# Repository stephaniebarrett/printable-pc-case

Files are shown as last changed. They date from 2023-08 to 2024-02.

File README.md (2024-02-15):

# 3D Printable Rackmount PC/Server Case using [OpenSCAD](https://openscad.org/).
## WIP
The goal of this project originally was to create OpenSCAD modules of PC components to facilitate the design of a modular rack-mountable computer chassis. But once that was complete, I began designing a chassis and somewhere to store it; so for now, here we are. 2.5 versions in and I still feel like this is very much a work in progress. As I complete test prints, and have new ideas, I will continue to iterate on the case design.

## Notes
### V1
While doing a full test print/fit, there were several issues with warping (especially the corner pieces) and cracking when transitioning from printing floor + walls to just the walls. However, they didn't seem to affect the build at all. The rear wall was the most fragile with fan/io/psu cutouts and some chunkier pieces to bolt sections together; I had one of those chunky pieces break off, and some issues with support material not cooperating while printing. The honeycomb fill needs some work, while nocking out its support material, most of the honeycomb broke off on 2 of the 3 fan openings.  The 3U test case is currently mounted in my rack with x4 Rack Studs in the center of the first and third 'U's. It has been extremely stable, however I still have concerns about the PSU somewhat unsupported at the rear of the case.

#### Exporting (batch file)
```
export.bat [options] main.scad
Allowed options:
	-t arg		Specifies the type of file to export: stl, png (may be used multiple times)
	-m arg		Specifies the type of model to export: cage, joinery, rack (may be used multiple times)
	-h arg		0 will remove the honeycomb fill, 1 will keep it.
```

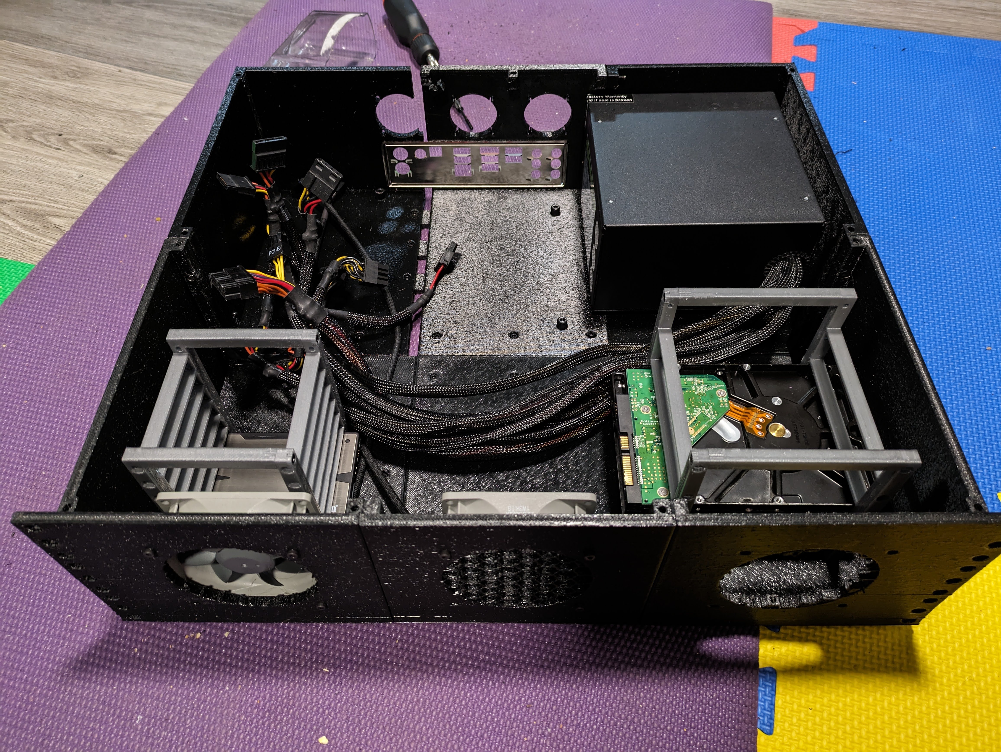
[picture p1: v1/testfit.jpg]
Chassis Test Fit V1 Test Fit


### V2 & V2-Compact
A complete redesign has enabled me to mitigate most of the cracking, warping, and support issues by building panels rather than sections. This means all of the panels can be printed flat on the build plate and the hex sections come out quite well. I moved the PSU to the front of the case, which required standing it on it's side to fit beside an ATX mainboard within a 19" rack. That also means I've had to go from a 3U design to a 4U to fit it on it's side, and you'll need to plug it in at the front. However, all of the heavy components are now at the front of the case, close to the supports, which has allowed some thinner walls and a somewhat simpler system of joining the panels together.

The compact version of the V2 case is almost identical. The most obvious difference is that the HDDs are mounted above the mainboard, allowing the case depth to be reduced by about 115mm

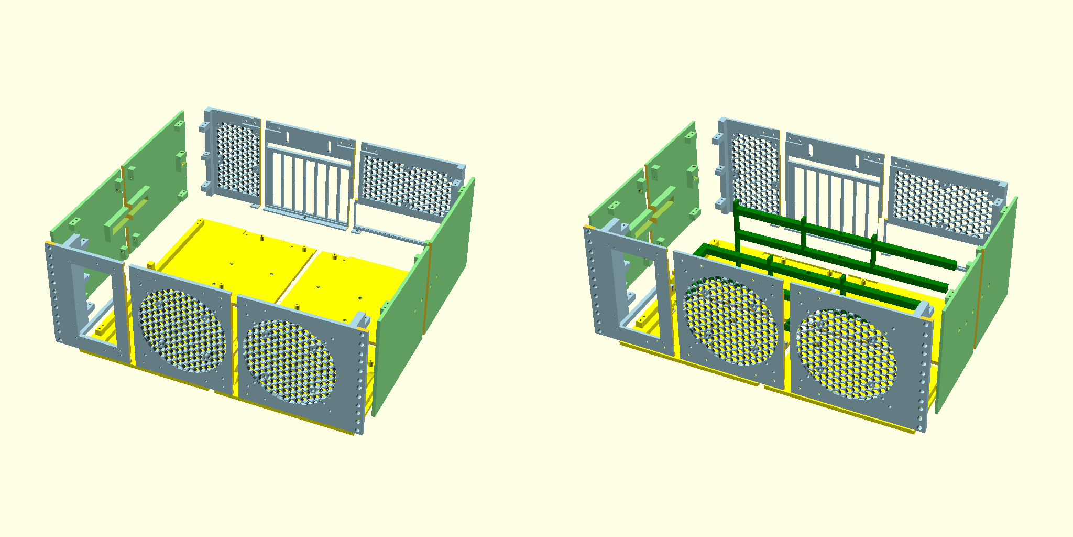
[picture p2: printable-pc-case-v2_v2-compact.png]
Chassis Rendering V2 & V2-Compact Rendering


#### Exporting (bash file)
```
Usage: ${0} [OPTION [ARGUMENT]]... main.scad

OPTIONS:
    -o, --out_path <filepath>                      Specify the output file path. Default: ./export
    -i, --in_file <filename>                       Specify the input .scad file. Default: main.scad
    -p, --panel front|left|right|top|bottom|back   Specify which panel to render.
    -j, --joinery                                  A toggle to render the joinery instead of the panel for the specified panel.
    -c, --cage                                     A toggle to render the HDD cage instead of any other geometry.
    -r, --resolution <value>                       The resolution of the exported .png thumbnail. Default: 1024.
    -a, --all                                      Exports all geometry. NOTE: very hardware intensive.
    -s                                             Exports an exploded view screenshot.
    -h, --help                                     Print this help message.
```

## Modules
Many of the modules approximate the physical dimensions of various PC components. These are used to estimate positions and clearances of all the printable parts. Most of the dimensions were pulled from spec sheets online, and the rest were measured from physical pc hardware.
### mainboard.scad
- ATX and Micro ATX models.
### psu.scad
- ATX model.
### hdd.scad
- 2.5" SSD & 3.5" HDD models.
### fan.scad
- 140mm, 120mm, 92mm, 80mm, 70mm, 60mm, 50mm, 40mm models and through holes for mounting and ducting.

## TODO
- support other mainboard formats (currently only mATX and ATX).
- support other PSU formats (currently only ATX).
- add more and better code comments
- ...

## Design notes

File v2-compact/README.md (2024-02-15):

# 3D Printable Rackmount PC/Server Case using [OpenSCAD](https://openscad.org/).
## WIP
The goal of this project originally was to create OpenSCAD modules of PC components to facilitate the design of a modular rack-mountable computer chassis. But once that was complete, I began designing a chassis and somewhere to store it; so for now, here we are. 2.5 versions in and I still feel like this is very much a work in progress. As I complete test prints, and have new ideas, I will continue to iterate on the case design.

## V2 & V2-Compact
A complete redesign has enebled me to mitigate most of the cracking, warping, and support issues by building panels rather than sections. This means all of the panels can be printed flat on the build plate and the hex sections come out quite well. I moved the PSU to the front of the case, which required standing it on it's side to fit beside an ATX mainboard within a 19" rack. That also means I've had to go from a 3U design to a 4U to fit it on it's side, and you'll need to plug it in at the front. However, all of the heavy components are now at the front of the case, close to the supports, which has allowed some thinner walls and a somewhat simpler system of joining the panels together.

The compact version of the V2 case is almost identical. The most obvious difference is that the HDDs are mounted above the mainboard, allowing the case depth to be reduced by about 115mm

Chassis Rendering V2 & V2-Compact Rendering

### Exporting (bash file)
```
Usage: ${0} [OPTION [ARGUMENT]]... main.scad

OPTIONS:
    -o, --out_path <filepath>                      Specify the output file path. Default: ./export
    -i, --in_file <filename>                       Specify the input .scad file. Default: main.scad
    -p, --panel front|left|right|top|bottom|back   Specify which panel to render.
    -j, --joinery                                  A toggle to render the joinery instead of the panel for the specified panel.
    -c, --cage                                     A toggle to render the HDD cage instead of any other geometry.
    -r, --resolution <value>                       The resolution of the exported .png thumbnail. Default: 1024.
    -a, --all                                      Exports all geometry. NOTE: very hardware intensive.
    -s                                             Exports an exploded view screenshot.
    -h, --help                                     Print this help message.
```
### Post Processing
- I have found that drilling out the M3 through holes with 7/64" drill bit is enough to clean the hole while still maintaining some friction.
- Depending on how severe your elephant's feet get, you may have to sand/scrape any of the mating surfaces to allow proper alignment and fit of sections of panels to be secured together.
### Hardware
#### 3.5" Drive Cage
- x4 M3x8 + nuts; for assembly
- x3 M3x18 (or M3x20), x1 M3x12 + nuts; for mounting
#### Front Panel
- x16 M3x6 (or M3x8) + nuts
#### Left Side Panel
- x4 M3x10 + nuts

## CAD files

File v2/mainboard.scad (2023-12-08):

include <global.scad>

translate([0, ATX_MB_DIMS[0], 0]) draw_ATX_mainboard();
draw_mATX_mainboard(true);

module draw_ATX_mainboard(center=false)
{
    offset = center ? [-ATX_MB_DIMS[0]/2, -ATX_MB_DIMS[1]/2, 0] : [0, 0, 0];
    draw_mainboard(offset, ATX_MB_DIMS, ATX_HOLES, 0);
}

module draw_mATX_mainboard(center=false)
{
    offset = center ? [-mATX_MB_DIMS[0]/2, -mATX_MB_DIMS[1]/2, 0] : [0, 0, 0];
    draw_mainboard(offset, mATX_MB_DIMS, mATX_HOLES, mATX_xOFFSET);
}

module draw_mainboard(offset, dims, holes, xOffset=0)
{
    translate(offset) difference()
    {
        cube(dims);
        draw_mainboard_mounting_holes (dims, holes, 5, MB_MOUNTING_HOLE_DIAMETER, xOffset);
        draw_rearIO_inset(xOffset);
    }
}

module draw_rearIO_inset(xOffset=0)
{
    translate([MB_IO_CUTOUT_OFFSET_X-xOffset, ATX_MB_DIMS[1], ATX_MB_DIMS[2]-.99]) difference()
    {
        translate([0,-25,0]) cube([159, 25, 1]);
        translate([5,-20,-.5]) cube([159-10, 20, 2]);
    }
}

function get_mainboard_mounting_hole_coord(idx, dims, positions, xOffset=0) = [
    INCH_TO_MM(MB_HOLE_LAYOUT_INCHES[positions[idx]][0] - xOffset), // x
    dims[1] - INCH_TO_MM(MB_HOLE_LAYOUT_INCHES[positions[idx]][1])  // y
];

module draw_mainboard_mounting_holes(dims, positions, height=10, diameter=MB_MOUNTING_HOLE_DIAMETER, xOffset=0)
{
    for (i = positions)
    {
        coord = MB_HOLE_LAYOUT_INCHES[i];
        x = INCH_TO_MM(coord[0]);
        y = INCH_TO_MM(coord[1]);
            
        translate ([x - xOffset, dims[1] - y, 0]) cylinder(h = height, d = diameter, center = true, $fn = 32);
    }
}



module draw_mainboard_standoffs(dims, positions, height=MB_STANDOFF_HEIGHT, diameter=MB_STANDOFF_OUTER_DIAMETER, xOffset=0)
{
    for (i = positions)
    {
        coord = MB_HOLE_LAYOUT_INCHES[i];
        x = INCH_TO_MM(coord[0]);
        y = INCH_TO_MM(coord[1]);
            
        translate ([x - xOffset, dims[1] - y, 0]) draw_mainboard_standoff(height, diameter);
    }
}

module draw_mainboard_standoff(height=MB_STANDOFF_HEIGHT, diameter=MB_STANDOFF_OUTER_DIAMETER)
{
    difference()
    {
        cylinder(h=height, d=diameter, center=true, $fn=32);
        // TODO: replace this cutout with enough space for a threaded insert
        cylinder(h=height+EPSILON, d=2.8, center = true, $fn=32);
    }
}

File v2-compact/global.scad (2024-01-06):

include <../ext/nutsnbolts/cyl_head_bolt.scad>;
include <../ext/honeycomb/honeycomb.scad>
include <../ext/OpenSCAD-Dovetails/dovetails.scad>

include <../lib/mainboard.scad>
include <../lib/psu.scad>
include <../lib/hdd.scad>
include <../lib/fan.scad>

// through holes
THcld  = 0.4; // dia clearance for the bolt
THhcld = 1.0; // dia clearances for the head
// nutcatch parallel
NPclh = 0.2; // nut height clearance
NPclk = 0.2; // clearance aditional to nominal key width
// nutcatch sidecut
NSclh = 0.2; // height clearance
NSclsl = 0.2; // slot width clearance

RACK_EAR_TYPE = "round"; // or "square"
RACK_EAR_HOLE_SIZE_ROUND = 7;
RACK_EAR_HOLE_SIZE_SQUARE = 9.4;
RACK_EAR_SIZE = [15.875, 6, 44.5];
RACK_EAR_HOLE_OFFSET = 6.35;
RACK_EAR_HOLE_SPACING = 15.875;

RACK_OUTER_WIDTH = 441;
RACK_OUTER_DEPTH = 285;
RACK_OUTER_HEIGHT = get_rack_height(4);

RACK_FLOOR_DIM = 6;
RACK_ROOF_DIM = 6;
RACK_WALL_DIM = 4;
RACK_FRONT_DIM = 4;
RACK_BACK_DIM = 4;

BUFFER = 11;

ATX_MB_POS = [RACK_OUTER_WIDTH-RACK_WALL_DIM-BUFFER*2-ATX_MB_DIMS[0], RACK_OUTER_DEPTH-RACK_BACK_DIM-ATX_MB_DIMS[1], RACK_FLOOR_DIM+MB_STANDOFF_HEIGHT+MB_OFFSET_Z];
ATX_PSU_POS = [RACK_WALL_DIM+BUFFER, RACK_FRONT_DIM+ATX_PSU_DIMS[1], RACK_FLOOR_DIM];

PCI_CUTOUT_DIMS = [16,RACK_BACK_DIM+EPSILON*2,103.5];
PCI_CUTOUT_X = [14.17,34.49,54.81,75.13,95.45,115.77,136.09];

// FRONT FAN POSITIONS
x = (RACK_OUTER_WIDTH-RACK_WALL_DIM-BUFFER-ATX_PSU_DIMS[2]-ATX_PSU_POS[0]-140*2) / 3;
xFan1 = RACK_OUTER_WIDTH-BUFFER-70-x;
xFan2 = RACK_OUTER_WIDTH-BUFFER-210-x*2;
xFanMid = xFan2+(xFan1-xFan2)/2;

xJ1 = xFanMid;
xJ2 = ATX_PSU_POS[0]+ATX_PSU_DIMS[2]+((xFan2-70)-(ATX_PSU_POS[0]+ATX_PSU_DIMS[2]))/2;

// HDD POSITIONS
hddHeight = (RACK_OUTER_HEIGHT-RACK_ROOF_DIM-RACK_FLOOR_DIM-HDD_35_DIMS[0])/2;
hddSpacing = HDD_35_DIMS[0]+5;
ssdSpacing = HDD_25_DIMS[2]+(140-HDD_25_DIMS[2]*6)/3;
yDrivePos = RACK_FRONT_DIM+FAN_DEPTH+BUFFER;

psuHeight = (RACK_OUTER_HEIGHT-RACK_FLOOR_DIM-RACK_ROOF_DIM-ATX_PSU_DIMS[0])/2;

// DOVETAILS
tail_width = 5;
tail_count = 1;
board_width = 10;
angle = 15;
board_thickness = 10;
pin_width = pin_width(tail_width = tail_width, tail_count=tail_count, board_width=board_width);

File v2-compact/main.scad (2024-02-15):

include <global.scad>

FRONT = 1;
LEFT = 1;
RIGHT = 1;
FLOOR = 1;
ROOF = 0;
BACK = 1;
JOINERY = 0;

EXPLODED = 0;
SECTION = 0;

MAINBOARD = 0;
FANS = 0;
PSU = 0;
DRIVES = 0;
DRIVE_CAGE = 0;

// MAINBOARD
if (MAINBOARD == 1)
{
    translate(ATX_MB_POS) draw_ATX_mainboard();
}

// FRONT FANS
if (FANS == 1)
{
    for (i = [/*80,120,*/140])
    {
        translate([xFan1,5,get_rack_height(4)/2-i/2]) translate([-i/2,0,0]) draw_fan(i,i,FAN_DEPTH);
        translate([xFan2,5,get_rack_height(4)/2-i/2]) translate([-i/2,0,0]) draw_fan(i,i,FAN_DEPTH);
    }
}

// PSU
if (PSU == 1)
{
    translate([RACK_WALL_DIM+BUFFER,0,RACK_FLOOR_DIM+psuHeight]) translate([0,RACK_FRONT_DIM+ATX_PSU_DIMS[1],0]) rotate([0,-90,180]) translate([ATX_PSU_DIMS[0],ATX_PSU_DIMS[1],0]) rotate([0,0,180]) draw_ATX_psu();
}

// DRIVES
if (DRIVES == 1)
{
    draw_drives();
}
if (DRIVE_CAGE == 1)
{
    color("green") draw_drive_cage();
}

// JOINERY
if (JOINERY == 1)
{
    if (BACK == 1)
    {
        difference()
        {
            union()
            {
                translate([RACK_WALL_DIM+BUFFER+87+152.65+6-30,RACK_OUTER_DEPTH-RACK_BACK_DIM,RACK_OUTER_HEIGHT-RACK_ROOF_DIM-14.5]) cube([60,RACK_BACK_DIM/2-0.5,10]);
                translate([RACK_WALL_DIM+BUFFER+85-30,RACK_OUTER_DEPTH-RACK_BACK_DIM,RACK_OUTER_HEIGHT-RACK_ROOF_DIM-14.5]) cube([60,RACK_BACK_DIM/2-0.5,10]);
                
                translate([RACK_WALL_DIM+BUFFER+87+152.65+6-9.5,RACK_OUTER_DEPTH-RACK_BACK_DIM-10,RACK_OUTER_HEIGHT-RACK_ROOF_DIM-5]) cube([20,RACK_BACK_DIM/2+10,5]);
                translate([RACK_WALL_DIM+BUFFER+85-9.5,RACK_OUTER_DEPTH-RACK_BACK_DIM-10,RACK_OUTER_HEIGHT-RACK_ROOF_DIM-5]) cube([20,RACK_BACK_DIM/2+10,5]);

            }
            draw_back_fasteners($fn=64);
        }
        
    }
    if (FRONT == 1)
    {
        difference()
        {
            union()
            {
                for (side = [xJ1, xJ2])
                {
                    translate([side-50,RACK_FRONT_DIM/2,RACK_OUTER_HEIGHT-RACK_ROOF_DIM-10-0.5]) cube([100,RACK_FRONT_DIM/2,10]);
                    translate([side-50,RACK_FRONT_DIM/2,RACK_FLOOR_DIM+0.5]) cube([100,RACK_FRONT_DIM/2,10]);
                    translate([side-3.5+25,RACK_FRONT_DIM,RACK_FLOOR_DIM+0.5]) cube([10,10,10]);
                    translate([side-8.5-25,RACK_FRONT_DIM,RACK_FLOOR_DIM+0.5]) cube([10,10,10]);
                    translate([side-3.5+25,RACK_FRONT_DIM,RACK_OUTER_HEIGHT-RACK_ROOF_DIM-10.5]) cube([10,10,10]);
                    translate([side-8.5-25,RACK_FRONT_DIM,RACK_OUTER_HEIGHT-RACK_ROOF_DIM-10.5]) cube([10,10,10]);
                }
            }
            draw_front_fasteners($fn=64);
        }
    }
    if (LEFT == 1)
    {
        difference()
        {
            translate([RACK_WALL_DIM+0.5,RACK_OUTER_DEPTH/2-50,RACK_OUTER_HEIGHT/2-5]) cube([9.5,100,10]);
            draw_left_side_fasteners($fn=64);
        }
    }
    if (RIGHT == 1)
    {
        difference()
        {
            translate([RACK_OUTER_WIDTH-RACK_WALL_DIM-10,RACK_OUTER_DEPTH/2-50,RACK_OUTER_HEIGHT/2-5]) cube([9.5,100,10]);
            draw_right_side_fasteners($fn=64);
        }
    }
    if (FLOOR == 1)
    {
        difference()
        {
            union()
            {
                difference()
                {
                    width = (RACK_OUTER_WIDTH-1)/2;
                    depth = (RACK_OUTER_DEPTH/2);
                    translate([RACK_OUTER_WIDTH/2,RACK_OUTER_DEPTH/2,1.5-EPSILON]) cube([width+10,depth+10,3],center=true);
                    translate([RACK_OUTER_WIDTH/2,RACK_OUTER_DEPTH/2,2-EPSILON*2]) cube([width-10,depth-10,4],center=true);
                }
                translate([RACK_OUTER_WIDTH/2,RACK_OUTER_DEPTH/2,1.5-EPSILON]) cube([20,20,3],center=true);
            }
            draw_floor_fasteners($fn=64);
        }
    }
    if (ROOF == 1)
    {
        difference()
        {
            union()
            {
                difference()
                {
                    width = (RACK_OUTER_WIDTH-1)/2;
                    depth = (RACK_OUTER_DEPTH/2);
                    translate([RACK_OUTER_WIDTH/2,RACK_OUTER_DEPTH/2,RACK_OUTER_HEIGHT-1.5+EPSILON]) cube([width+10,depth+10,3],center=true);
                    translate([RACK_OUTER_WIDTH/2,RACK_OUTER_DEPTH/2,RACK_OUTER_HEIGHT-2+EPSILON*2]) cube([width-10,depth-10,4],center=true);
                }
                translate([RACK_OUTER_WIDTH/2,RACK_OUTER_DEPTH/2,RACK_OUTER_HEIGHT-1.5+EPSILON]) cube([20,20,3],center=true);
            }
            draw_roof_fasteners($fn=64);
        }
    }
}
// RACK PANELS
else
{
    if (FLOOR == 1)
    {
        if (EXPLODED == 1)
            draw_floor_exploded();
        else
            draw_floor_section(SECTION);
    }
    if (LEFT == 1)
    {
        if (EXPLODED == 1)
            draw_left_panel_exploded();
        else
            draw_left_panel_section(SECTION);
    }
    if (RIGHT == 1)
    {
        if (EXPLODED == 1)
            draw_right_panel_exploded();
        else
            draw_right_panel_section(SECTION);
    }
    if (ROOF == 1)
    {
        if (EXPLODED == 1)
            draw_roof_panel_exploded();
        else
            draw_roof_panel_section(SECTION);
    }
    if (BACK == 1)
    {
        if (EXPLODED == 1)
            draw_back_panel_exploded();
        else
            draw_back_panel_section(SECTION);
    }
    if (FRONT == 1)
    {
        if (EXPLODED == 1)
            draw_front_panel_exploded();
        else
            draw_front_panel_section(SECTION);
    }
}

// PANELS
module draw_roof_panel_exploded()
{
    for(x=[0,1])
    {
        for(y=[0,1])
        {
            i = y*2+x+1;
            translate([10*x,10*y,30]) draw_roof_panel_section(i);
        }
    }
}

module draw_roof_panel_section(section=0)
{
    intersection()
    {
        difference()
        {
            color("yellow") translate([0,0,RACK_OUTER_HEIGHT-RACK_ROOF_DIM]) union()
            {
                translate([0,RACK_FRONT_DIM,0]) cube([RACK_OUTER_WIDTH, RACK_OUTER_DEPTH-RACK_FRONT_DIM, RACK_ROOF_DIM]);
                // wall mounting points
                translate([RACK_WALL_DIM,RACK_FRONT_DIM+40.5,-10]) cube([10,RACK_OUTER_DEPTH-RACK_FRONT_DIM-RACK_BACK_DIM-51,10]);
                translate([RACK_OUTER_WIDTH-RACK_WALL_DIM-10,RACK_FRONT_DIM+40.5,-10]) cube([10,RACK_OUTER_DEPTH-RACK_FRONT_DIM-RACK_BACK_DIM-51,10]);
                translate([RACK_WALL_DIM,RACK_OUTER_DEPTH/2-10,-30]) cube([10,20,20]);
                translate([RACK_OUTER_WIDTH-RACK_WALL_DIM-10,RACK_OUTER_DEPTH/2-10,-30]) cube([10,20,20]);
            }
            // joinery
            width = (RACK_OUTER_WIDTH-1)/2;
            depth = (RACK_OUTER_DEPTH/2);
            difference()
            {
                translate([RACK_OUTER_WIDTH/2,RACK_OUTER_DEPTH/2,RACK_OUTER_HEIGHT-1.5+EPSILON]) cube([width+11,depth+11,3],center=true);
                translate([RACK_OUTER_WIDTH/2,RACK_OUTER_DEPTH/2,RACK_OUTER_HEIGHT-2+EPSILON*2]) cube([width-11,depth-11,4],center=true);
            }
            translate([RACK_OUTER_WIDTH/2,RACK_OUTER_DEPTH/2,RACK_OUTER_HEIGHT-1.5+EPSILON]) cube([21,21,3],center=true);

            draw_left_side_fasteners($fn=64);
            draw_right_side_fasteners($fn=64);
            draw_front_fasteners($fn=64);
            draw_back_fasteners($fn=64);
            draw_roof_fasteners($fn=64);
        }
    
        if (section == 0)
            translate([-EPSILON,-EPSILON,-EPSILON]) cube([RACK_OUTER_WIDTH+EPSILON*2,RACK_OUTER_DEPTH+EPSILON*2, RACK_OUTER_HEIGHT+EPSILON*2]);
        else if (section == 1)
            translate([-EPSILON,-EPSILON,-EPSILON]) cube([RACK_OUTER_WIDTH/2+EPSILON,RACK_OUTER_DEPTH/2+EPSILON, RACK_OUTER_HEIGHT+EPSILON*2]);
        else if (section == 2)
            translate([RACK_OUTER_WIDTH/2,-EPSILON,-EPSILON]) cube([RACK_OUTER_WIDTH/2+EPSILON,RACK_OUTER_DEPTH/2+EPSILON, RACK_OUTER_HEIGHT+EPSILON*2]);
        else if (section == 3)
            translate([-EPSILON,RACK_OUTER_DEPTH/2,-EPSILON]) cube([RACK_OUTER_WIDTH/2+EPSILON,RACK_OUTER_DEPTH/2+EPSILON, RACK_OUTER_HEIGHT+EPSILON*2]);
        else if (section == 4)
            translate([RACK_OUTER_WIDTH/2,RACK_OUTER_DEPTH/2,-EPSILON]) cube([RACK_OUTER_WIDTH/2+EPSILON,RACK_OUTER_DEPTH/2+EPSILON, RACK_OUTER_HEIGHT+EPSILON*2]);
    }
}

module draw_back_panel_exploded()
{
    for (i = [0:2])
    {
        translate([10*i,40,0]) draw_back_panel_section(i+1);
    }
}
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

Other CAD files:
v2/fan.scad
ext/honeycomb/honeycomb.scad
v1/global.scad
v1/main.scad
v1/psu.scad
v1/rack.scad
v2/global.scad
v2/main.scad

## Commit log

2023-07-13 Removed the main 'mainboard' module as it served no real purpose. Renamed constants and modules for clarity, consistency, and to prevent clashes with other files.
    [mainboard.scad]
2023-07-13 fleshed out a basic ATX PSU model with mounting hole locations.
    there is some extra math & logic here to rotate the whole model to match the mainboard orientation, mainly because i was too lazy to translate the mounting hole locations from the spec sheet coordina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
    [psu.scad]
2023-07-13 added hdd.scad, rack.scad, utiltiy.scad, and main.scad
    added hdd.scad, rack.scad, utiltiy.scad, and main.scad. more renaming modules for consistency. added get_ATX_psu_dims(), get_ATX_mainboard_dims(), and get_mATX_mainboard_dims()
    [hdd.scad, main.scad, mainboard.scad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]
2023-07-13 added hdd.scad, EPSILON constant, lots of updates for generating all of the base parts
    [fan.scad, hdd.scad, main.scad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]
2023-07-17 added Alpha (text rendering) and NutsNBolts (fasteners) as git submodules, as well as providing a copy of honeycomb.scad
    [main.scad]
2023-07-19 added $fn to fan.scad cylinders
    [fan.scad]
2023-07-19 lots of work on splitting up the rack structure to allow printing (20x20x20 print area) and adding tabs and fastener locations for reassembly
    [main.scad, rack.scad]
2023-07-19 refactor; moved all global constants into globals.scad for access by all modules and removed the "getters" that were basically redundant. merged utility.scad into global.scad
    [fan.scad, global.scad, hdd.scad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]
2023-07-19 some work on the rear half of the case
    [global.scad, main.scad, rack.scad]
2023-07-28 added more fan sizes; 40mm to 120mm
    [fan.scad]
2023-07-28 added mainboard standoff modules, added rear fans to rack, added mounting points to rack, added joinery to connect front and back sections of rack
    [global.scad, main.scad, mainboard.scad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]
2023-08-09 hdd cage and other changes to support it
    [global.scad, hdd.scad, main.scad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]
2023-08-09 windows script to output all .stl models
2023-08-09 added .gitignore for .stl and .3mf
2023-08-09 added some global tolerances for fasteners
    [global.scad, hdd.scad, rack.scad]
2023-08-10 reduced rack width; made psu position adjustments. removed module connection tabs that were right against the front & back walls. re-added missing rack ears. adjusted geometry of underside joinery
    [global.scad, rack.scad]
2023-08-11 rework to support 2.5" drives & matching cage. rewrite of Rack Front, there seemed to be some position inconsitencies
    [global.scad, hdd.scad, main.scad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]
2023-08-11 helper function to get the width of a drive cage
    [hdd.scad]
2023-08-11 added support for a front left ssd drive cage
    [main.scad, rack.scad]
2023-08-12 progress on adding support for optional heat set inserts instead of captive nuts on various parts: drive cage, and front/sides of rack have been updated.
    [global.scad, hdd.scad, rack.scad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]
2023-08-12 added more rack heat set inserts, added option for round rack ear holes, some rack code cleanup
    [global.scad, rack.scad]
2023-08-12 added rendering of chassis
2023-08-12 re-worked the draw_hdd_cage_riser and draw_hdd_cage modules of hdd.scad; added mounting holes for drives instead of nubs
    [hdd.scad, rack.scad]
2023-08-13 adjusted fastener tolerances. shifted drive cage shelves up to allow space for heat sets
    [global.scad, hdd.scad, rack.scad]
2023-08-14 added support for an alternate case layout, with a vertical 3.5" drive cage, and some export script modifications to keep the directory a little more tidy
    [global.scad, hdd.scad, main.scad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]
2023-08-15 removed ghosts from main and added a default option to render the whole case
    [main.scad]
2023-08-18 fixed the z height of the 3.5 drive dims, hacked in a fix to flip 3.5 drives for the horizontal cage so mounting screws weren't interfereing with each other
    [global.scad, hdd.scad]
2023-08-23 I found out that the printed hex grills were very fragile, so adding a flag to add them or not
    [global.scad, rack.scad]
2023-08-25 updating readme with test print photo and notes
2023-12-08 first pass at version 2 of the case; currently just copied the externals into here for now
    [fan.scad, global.scad, hdd.scad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]
2023-12-08 rotated hdd to vertical to shorten the case enough that we can use 2 print sections rather than 3
    [main.scad]
2023-12-11 added wall and floor joinery & fasteners
    [main.scad]
2023-12-17 working on the rear panel
    [global.scad, main.scad]
2023-12-18 fixed rear panel fan mounting holes
    [main.scad]
2023-12-18 playing with PCI cutouts/supports
    [ATX_MB_Card_Support.STL, main.scad]
2023-12-19 moved first version of the case into 'v1'
    [fan.scad, global.scad, hdd.scad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]
2023-12-19 tweaking the back panel and splitting it into sections; will need to figure out joinery
    [ATX_MB_Card_Support.STL, main.scad]
2023-12-19 more back panel joinery/fasteners
    [main.scad]
2023-12-19 fixed an issue with rendering individual back sections
    [main.scad]
2023-12-25 added joinery to the roof and joinery & fastener tweaks on roof/floor to fit Prusa mk3 print bed.
    [main.scad]
2024-01-04 cleaned up a few triangles on the floor, flipped some lower front fasteners, added a generation script
    [main.scad]
2024-01-05 added a screenshot option to the script that renders an exploded view of the case
2024-01-05 removed hard-coded values for roof/floor joinery sizes
    [main.scad]
2024-01-06 massive cleanup; pc component files and generic utilities have been moved into a lib folder that is now shared by all case versions. as well, externals are now in a shared ext folder.
    [dovetails.scad, fan.scad, global.scad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]
2024-01-06 re-added nutsbolts submodule and updated dovetails to a submodule
    [dovetails.scad]
2024-01-06 forgot to add v2 globals for submodule changes
    [global.scad]
2024-02-15 removed dovetails (too difficult to assemble) & adjusted buffer space on mounting points & adjusted positions on side nut catches that were burried
    [main.scad]
